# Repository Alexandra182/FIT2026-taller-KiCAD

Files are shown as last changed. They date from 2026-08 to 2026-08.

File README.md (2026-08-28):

# PicoFlutter — Reto de ruteo / Routing Challenge

*(English version below)*

## El reto

PicoFlutter es una placa "mariposa" basada en el microcontrolador **RP2040**, con
LEDs RGB WS2812B, USB-C, memoria flash QSPI y cargador de batería LiPo.

El esquemático está terminado y todos los componentes ya están colocados en la
placa — **pero no hay ninguna pista**. Tu misión: **rutear la placa completa**.

## Cómo empezar

1. Abre `picoflutter.kicad_pro` en KiCad.
2. Abre el editor de PCB. Verás los 67 componentes colocados y el *ratsnest*
   (las líneas finas que indican qué pads deben conectarse entre sí).
3. Rutea con la herramienta **Route Tracks** (tecla `X`). Usa `V` para cambiar
   de capa insertando una vía.
4. Cuando termines, ejecuta **Inspect → Design Rules Checker (DRC)**:
   el objetivo es **0 errores** y ninguna conexión sin rutear.

## Datos de la placa

| Parámetro | Valor |
|---|---|
| Tamaño | 70.5 × 55 mm |
| Capas de cobre | 4 (F.Cu, In1.Cu, In2.Cu, B.Cu) |
| Componentes | 67 |
| Redes (nets) | 92 |
| Ancho mínimo de pista | 0.2 mm |
| Separación mínima (clearance) | 0.13 mm |
| Vía mínima | 0.45 mm de diámetro |

Las clases de red ya están configuradas en el proyecto (`Default`, `MCUpow`,
`lowpow`, `signals`) — KiCad aplicará el ancho y la separación correctos
automáticamente según la red que estés ruteando.

## Consejos

- **Alimentación primero:** rutea USB-C → cargador (MCP73831) → reguladores →
  RP2040 antes que las señales. Las pistas de alimentación son más anchas.
- **Aprovecha las 4 capas:** una estrategia clásica es dedicar una capa interna
  a **GND** y otra a **3.3 V** usando zonas de cobre (Add Filled Zone), y dejar
  las capas externas para señales.
- **QSPI:** las pistas entre el RP2040 y la flash W25Q64 deben ser cortas y
  directas.
- **Cristal:** mantén el cristal de 12 MHz cerca del RP2040 y no pases señales
  ruidosas por debajo.
- **USB:** el par diferencial USB (D+/D−) se rutea junto, con la herramienta
  **Route Differential Pair** (tecla `6`).
- Reordena el *ratsnest* pulsando `B` (rellenar zonas) y usa `Ctrl+Z` sin miedo.

¿Terminaste con 0 errores de DRC? Compara tu ruteo con el de tus compañeros:
¿quién usó menos vías? ¿quién tiene las pistas más cortas?
(Estadísticas en **Inspect → Board Statistics**.)

---

## The challenge (English)

PicoFlutter is a butterfly-shaped board built around the **RP2040**
microcontroller, with WS2812B RGB LEDs, USB-C, QSPI flash and a LiPo battery
charger.

The schematic is finished and every component is already placed on the board —
**but there are no tracks**. Your mission: **route the entire board**.

1. Open `picoflutter.kicad_pro` in KiCad and enter the PCB editor.
2. The ratsnest (thin lines) shows which pads must be connected.
3. Route with `X`, drop vias with `V`. Net classes are already configured, so
   track widths and clearances are applied automatically.
4. You are done when **DRC reports 0 errors and 0 unrouted connections**.

Tips: route power before signals; on this 4-layer board a classic strategy is
an inner GND plane plus an inner 3.3 V plane (filled zones), signals on the
outer layers. Keep the QSPI flash and the 12 MHz crystal close to the RP2040,
and route USB D+/D− as a differential pair (`6`).

Finished? Compare via count and total track length with your classmates in
**Inspect → Board Statistics**.

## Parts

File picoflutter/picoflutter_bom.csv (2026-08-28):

Reference | Value | Footprint | Qty | DNP | Part No
C1,C2 | 4.7u | Capacitor_SMD:C_0603_1608Metric | 2
C3,C7,C8,C10,C12,C13,C14,C15,C16,C17 | 100n | Capacitor_SMD:C_0402_1005Metric | 10
C4,C5 | 27p | Capacitor_SMD:C_0402_1005Metric | 2
C6,C20 | 10uF | Capacitor_SMD:C_0805_2012Metric | 2
C9,C11 | 1u | Capacitor_SMD:C_0402_1005Metric | 2
CHG1 | ORANGE | LED_SMD:LED_0402_1005Metric | 1
D2 | MBR0540 | Diode_SMD:D_SOD-123 | 1
IC1 | AP7361EA-33E-13 | AP7361EA-33E-13:SOT230P700X180-4N | 1
IC3 | W25Q64JVZPIQ | W25Q64JVXGIQ:SON80P400X400X50-9N | 1
J2 | SM04B-SRSS-TB | SM04B-SRSS-TB:SM04BSRSSTB | 1
J4 | S2B-PH-SM4-TB(LF)(SN) | Connector_JST:JST_PH_S2B-PH-SM4-TB_1x02-1MP_P2.00mm_Horizontal | 1
J5 | USB4105-GF-A | USB4105-GF-A:GCT_USB4105-GF-A | 1 |  | USB4105-GF-A
LED1,LED2,LED3,LED4,LED5,LED6,LED7,LED8,LED9,LED10,LED11,LED12,LED13,LED14,LED15,LED16,LED17,LED18,LED19,LED20,LED21,LED22,LED23,LED24,LED25,LED26 | 1010RGBC-WS2812B | XL-1010RGBC-WS2812B:SMD4_XL-1010RGBC_XLG | 26
Q1 | DMG3415 | Package_TO_SOT_SMD:SOT-23 | 1
R1,R5 | 10K | Resistor_SMD:R_0402_1005Metric | 2
R2 | 5.1K | Resistor_SMD:R_0402_1005Metric | 1
R3,R4 | 5k1 | Resistor_SMD:R_0201_0603Metric | 2 |  | AF0201FR-075K1L
R26,R27 | 1k | Resistor_SMD:R_0402_1005Metric | 2
R28 | DNF | Resistor_SMD:R_0402_1005Metric | 1
R29,R30 | 27 | Resistor_SMD:R_0402_1005Metric | 2
S1 | TS-1088-AR02016 | TS-1088-AR02016:SW_TS-1088-AR02016 | 1
SW2 | MK-12C02-G020 | SlideSwitch:MK-12C02-G020_GSW | 1
U1 | MCP73831T-2ACI/OT | MCP73831T-2ACI:SOT95P270X145-5N | 1
U3 | RP2040 | RP2040_minimal:RP2040-QFN-56 | 1
Y1 | 445I23D12M00000 | 445I23D12M00000:445I23D24M00000 | 1

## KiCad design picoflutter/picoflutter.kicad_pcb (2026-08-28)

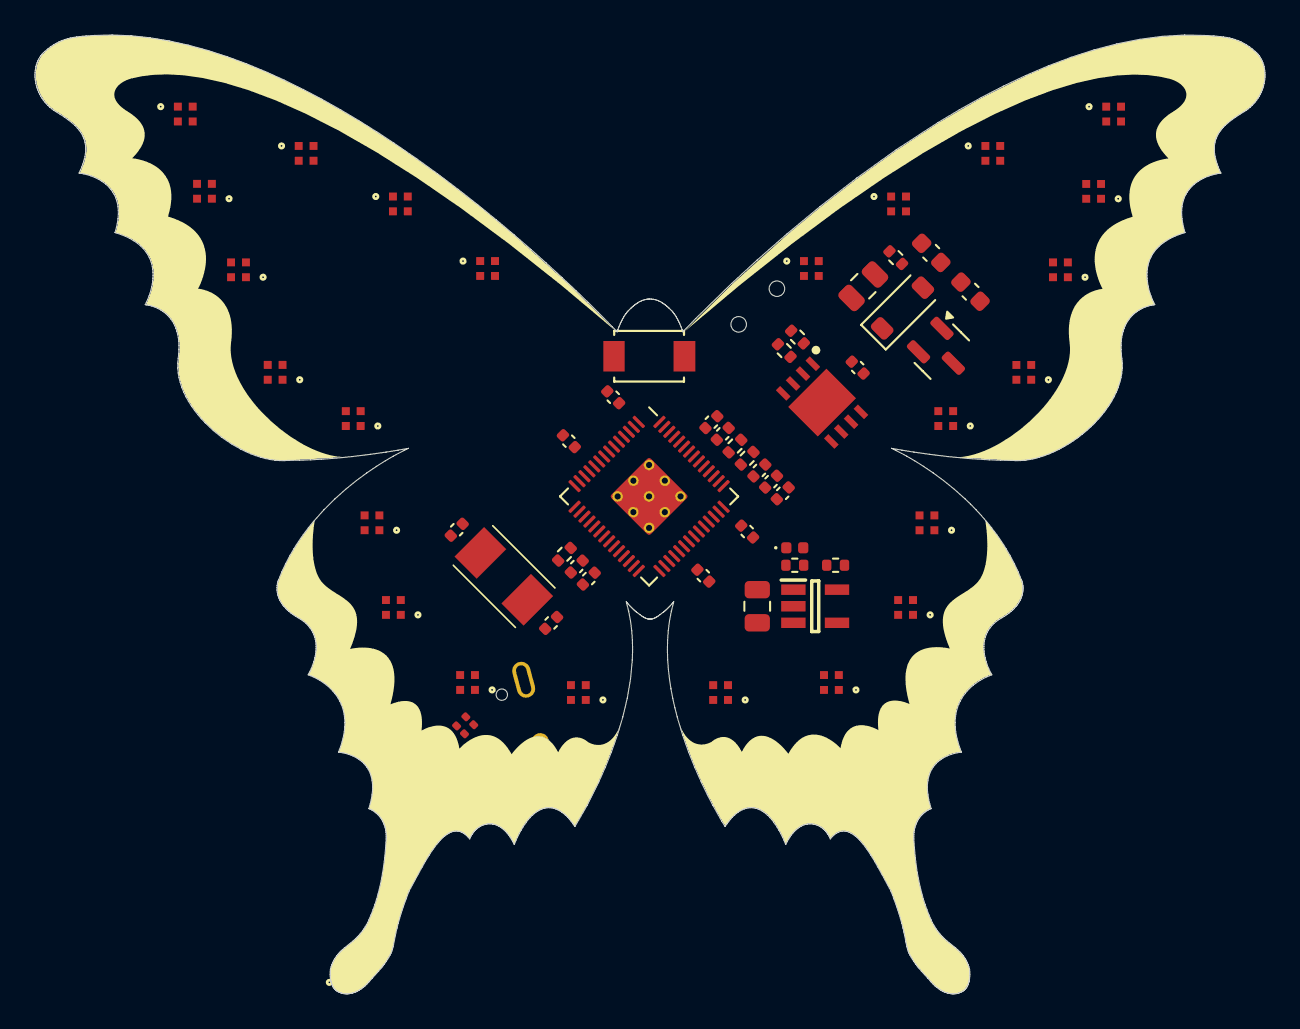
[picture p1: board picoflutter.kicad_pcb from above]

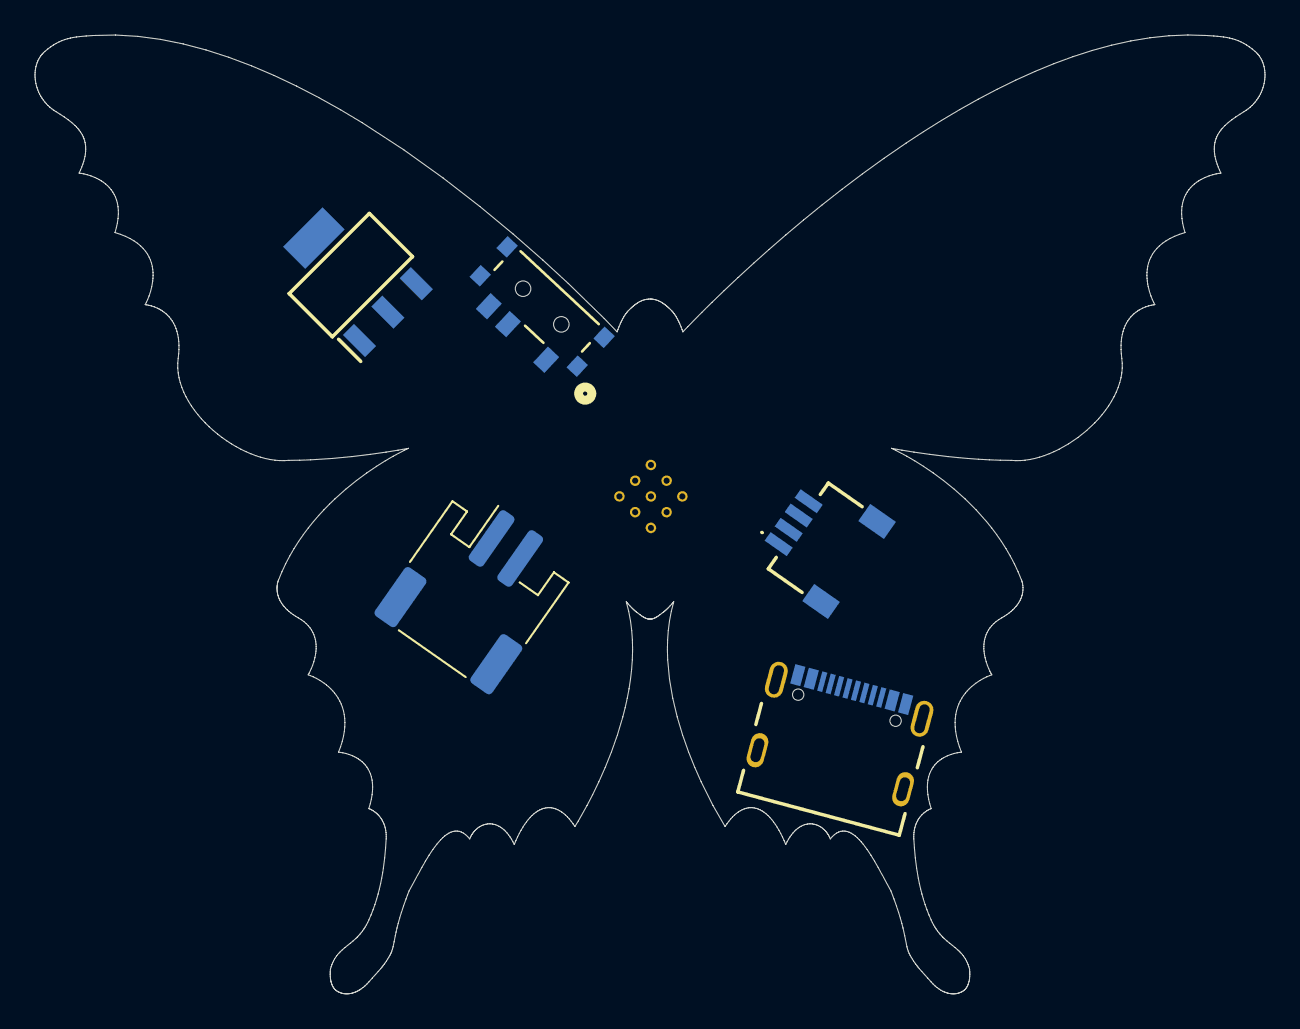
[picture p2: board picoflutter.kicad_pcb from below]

Board: 4 copper layers, 70.5 x 55.0 mm, 67 parts (5 on the bottom side), 54 nets, no tracks yet.

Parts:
C1, C2: 4.7u; C_0603_1608Metric
C3, C7, C8, C10, C12, C13, C14, C15, C16, C17: 100n; C_0402_1005Metric
C4, C5: 27p; C_0402_1005Metric
C6, C20: 10uF; C_0805_2012Metric
C9, C11: 1u; C_0402_1005Metric
CHG1: ORANGE; LED_0402_1005Metric
D2: MBR0540; D_SOD-123
IC1: AP7361EA-33E-13; SOT230P700X180-4N
IC3: W25Q64JVZPIQ; SON80P400X400X50-9N
J2: SM04B-SRSS-TB; SM04BSRSSTB
J4: S2B-PH-SM4-TB(LF)(SN); JST_PH_S2B-PH-SM4-TB_1x02-1MP_P2.00mm_Horizontal
J5: USB4105-GF-A; GCT_USB4105-GF-A
LED1, LED2, LED3, LED4, LED5, LED6, LED7, LED8, LED9, LED10, LED11, LED12, LED13, LED14, LED15, LED16, LED17, LED18, LED19, LED20, LED21, LED22, LED23, LED24, LED25, LED26: 1010RGBC-WS2812B; SMD4_XL-1010RGBC_XLG
Q1: DMG3415; SOT-23
R1, R5: 10K; R_0402_1005Metric
R2: 5.1K; R_0402_1005Metric
R3, R4: 5k1; R_0201_0603Metric
R26, R27: 1k; R_0402_1005Metric
R28: DNF; R_0402_1005Metric
R29, R30: 27; R_0402_1005Metric
S1: TS-1088-AR02016; SW_TS-1088-AR02016
SW2: MK-12C02-G020; MK-12C02-G020_GSW
U1: MCP73831T-2ACI/OT; SOT95P270X145-5N
U3: RP2040; RP2040-QFN-56
Y1: 445I23D12M00000; 445I23D24M00000

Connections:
I2C_SCL: J2.4, U3.3 (GPIO1)
I2C_SDA: J2.3, U3.2 (GPIO0)
+1V1: C7.1, C8.1, C9.1, U3.23 (DVDD), U3.45 (VREG_VOUT), U3.50 (DVDD)
+3V3: C2.1, C3.1, C10.1, C11.1, C12.1, C13.1, C14.1, C15.1, C16.1, C17.1, IC1.3 (OUT), IC3.8 (VCC), J2.2, R28.1, U3.1 (IOVDD), U3.10 (IOVDD), U3.22 (IOVDD), U3.33 (IOVDD), U3.42 (IOVDD), U3.43 (ADC_AVDD), U3.44 (VREG_IN), U3.48 (USB_VDD), U3.49 (IOVDD)
+5V: C1.1, IC1.1 (IN), LED1.2 (VDD), LED2.2 (VDD), LED3.2 (VDD), LED4.2 (VDD), LED5.2 (VDD), LED6.2 (VDD), LED7.2 (VDD), LED8.2 (VDD), LED9.2 (VDD), LED10.2 (VDD), LED11.2 (VDD), LED12.2 (VDD), LED13.2 (VDD), LED14.2 (VDD), LED15.2 (VDD), LED16.2 (VDD), LED17.2 (VDD), LED18.2 (VDD), LED19.2 (VDD), LED20.2 (VDD), LED21.2 (VDD), LED22.2 (VDD), LED23.2 (VDD), LED24.2 (VDD), LED25.2 (VDD), LED26.2 (VDD), SW2.3
/QSPI_SCLK: IC3.6 (CLK), U3.52 (QSPI_SCLK)
/QSPI_SD0: IC3.5 (DI(IO0)), U3.53 (QSPI_SD0)
/QSPI_SD1: IC3.2 (DO(IO1)), U3.55 (QSPI_SD1)
/QSPI_SD2: IC3.3 (IO2), U3.54 (QSPI_SD2)
/QSPI_SD3: IC3.7 (IO3), U3.51 (QSPI_SD3)
/QSPI_SS: IC3.1 (~CS), R27.1, R28.2, U3.56 (QSPI_SS)
/XIN: C4.1, U3.20 (XIN), Y1.2
/XOUT: R26.1, U3.21 (XOUT)
/~USB_BOOT: R27.2, S1.2
GND: C1.2, C2.2, C3.2, C4.2, C5.2, C6.2, C7.2, C8.2, C9.2, C10.2, C11.2, C12.2, C13.2, C14.2, C15.2, C16.2, C17.2, C20.2, IC1.2 (GND_1), IC1.4 (GND_2), IC3.4 (GND), J2.1, J4.1, J5.A1_B12 (GND), J5.B1_A12 (GND), J5.S1 (SHELL_GND), J5.S2 (SHELL_GND), J5.S3 (SHELL_GND), J5.S4 (SHELL_GND), LED1.3 (GND), LED2.3 (GND), LED3.3 (GND), LED4.3 (GND), LED5.3 (GND), LED6.3 (GND), LED7.3 (GND), LED8.3 (GND), LED9.3 (GND), LED10.3 (GND), LED11.3 (GND), LED12.3 (GND), LED13.3 (GND), LED14.3 (GND), LED15.3 (GND), LED16.3 (GND), LED17.3 (GND), LED18.3 (GND), LED19.3 (GND), LED20.3 (GND), LED21.3 (GND), LED22.3 (GND), LED23.3 (GND), LED24.3 (GND), LED25.3 (GND), LED26.3 (GND), R2.2, R3.1, R4.1, R5.1, S1.1, U1.2 (VSS), U3.19 (TESTEN), U3.57 (GND)
NEOPIXELS: LED1.4 (DIN), U3.4 (GPIO2)
unnamed: C5.1, R26.2, Y1.1
unnamed: CHG1.1 (C), R1.1
unnamed: C20.1, D2.1 (C), Q1.2 (S), SW2.1
unnamed: J5.A5 (CC1), R4.2
unnamed: J5.B5 (CC2), R3.2
unnamed: LED1.1 (DOUT), LED2.4 (DIN)
unnamed: LED2.1 (DOUT), LED3.4 (DIN)
unnamed: LED3.1 (DOUT), LED4.4 (DIN)
unnamed: LED4.1 (DOUT), LED5.4 (DIN)
unnamed: LED5.1 (DOUT), LED6.4 (DIN)
unnamed: LED6.1 (DOUT), LED7.4 (DIN)
unnamed: LED7.1 (DOUT), LED8.4 (DIN)
unnamed: LED8.1 (DOUT), LED9.4 (DIN)
unnamed: LED9.1 (DOUT), LED10.4 (DIN)
unnamed: LED10.1 (DOUT), LED11.4 (DIN)
unnamed: LED11.1 (DOUT), LED12.4 (DIN)
unnamed: LED12.1 (DOUT), LED13.4 (DIN)
unnamed: LED13.1 (DOUT), LED14.4 (DIN)
unnamed: LED14.1 (DOUT), LED15.4 (DIN)
unnamed: LED15.1 (DOUT), LED16.4 (DIN)
unnamed: LED16.1 (DOUT), LED17.4 (DIN)
unnamed: LED17.1 (DOUT), LED18.4 (DIN)
unnamed: LED18.1 (DOUT), LED19.4 (DIN)
unnamed: LED19.1 (DOUT), LED20.4 (DIN)
unnamed: LED20.1 (DOUT), LED21.4 (DIN)
unnamed: LED21.1 (DOUT), LED22.4 (DIN)
unnamed: LED22.1 (DOUT), LED23.4 (DIN)
unnamed: LED23.1 (DOUT), LED24.4 (DIN)
unnamed: LED24.1 (DOUT), LED25.4 (DIN)
unnamed: LED25.1 (DOUT), LED26.4 (DIN)
unnamed: R2.1, U1.5 (PROG)
unnamed: R1.2, U1.1 (STAT)
unnamed: R30.2, U3.46 (USB_DM)
unnamed: R29.2, U3.47 (USB_DP)
USB_D+: J5.A6 (DP1), J5.B6 (DP2), R29.1
USB_D-: J5.A7 (DN1), J5.B7 (DN2), R30.1
VBAT: C6.1, J4.2, Q1.3 (D), U1.3 (VBAT)
VBUS: CHG1.2 (A), D2.2 (A), J5.A4_B9 (VBUS), J5.B4_A9 (VBUS), Q1.1 (G), R5.2, U1.4 (VDD)

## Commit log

2026-08-28 Add picoflutter routing challenge (components placed, routing removed)
    PicoFlutter RP2040 board with schematic, placed components and project
    libraries; all tracks, vias and copper zones stripped so students route
    the board themselves. README describes the challenge (ES/EN).
    Claude-Session: https://claude.ai/code/session_01CTpVuugoA5qMQu3t31zp5N
    [picoflutter.kicad_pcb, picoflutter.kicad_sch, picoflutter_bom.csv]
2026-08-28 Move README to repo root, remove generated ibom, KiCad resave
    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
    [picoflutter.kicad_pcb, picoflutter.kicad_sch]
2026-08-28 Fix malformed board outline: remove 58 zero-length Edge.Cuts segments
    Degenerate lines (likely from the original artwork import) broke KiCad's
    outline chaining, so the 3D viewer fell back to a bounding box. Outline
    now resolves to a single closed contour; verified with a 3D render.
    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
    [picoflutter.kicad_pcb]
